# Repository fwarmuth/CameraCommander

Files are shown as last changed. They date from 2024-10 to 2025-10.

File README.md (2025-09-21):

# CameraCommander

Two stepper motors drive pan and tilt. A4988 drivers connect to an ESP8266 (target: ESP32) that keeps motion state and speaks a small serial protocol. A Raspberry Pi Zero 2 runs the Python app: configures the camera via gphoto2, stores images, controls the ESP over serial, and serves a web UI for focus, exposure tests (ISO, aperture), and tripod movement/settings.

What it looks like:

### First moving tripod prototype:
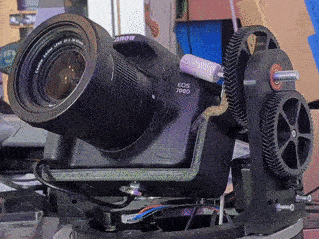
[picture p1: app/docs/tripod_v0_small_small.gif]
Tripod prototype


### Part design (via Freecad):
<!-- ![Top view of the concept](hardware/top.png){width="10px"}
![Buttom view of the concept](hardware/bot.png) -->
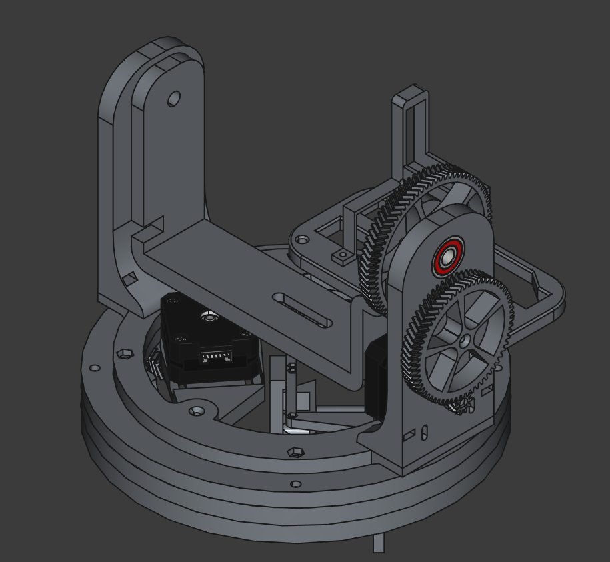
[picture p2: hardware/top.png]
Top view of the concept

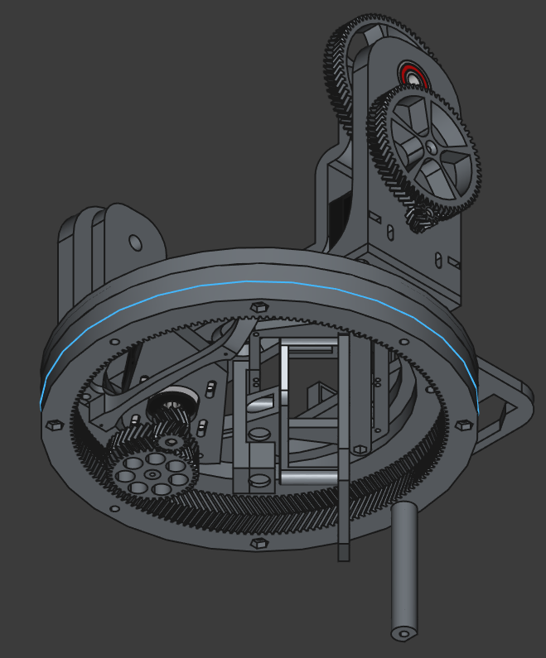
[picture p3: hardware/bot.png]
Bottom view of the concept


### Example result time-lapse:
Just camera controls, north of Kiruna, Sweden.

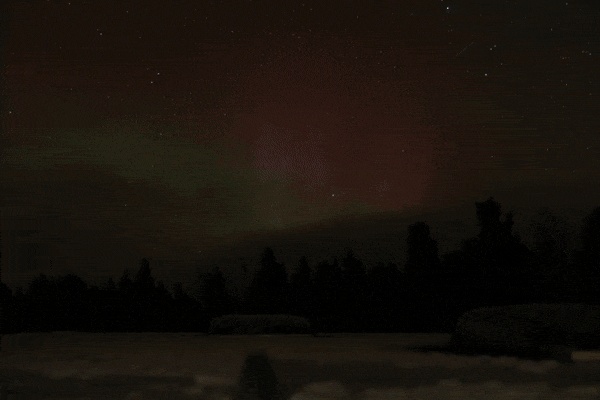
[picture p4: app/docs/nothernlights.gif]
Timelapse example


## Quick Start

- App (Python)
  - Requires: Python 3.11+, libgphoto2, ffmpeg (for video), a serial port for the tripod.
  - Run without installing (uv):
    - `cd app`
    - `uv run cameracommander --help`
  - Or install locally:
    - `cd app`
    - `pip install -e .`
    - `cameracommander --help`
  - Use:
    - Build a config: `cameracommander ui` (opens http://localhost:8000)
    - Test shot: `cameracommander snapshot settings.yaml out.jpg`
    - Timelapse: `cameracommander timelapse settings.yaml`

- Firmware (ESP8266)
  - Requires: PlatformIO CLI, NodeMCU v3 (ESP8266), step/dir drivers (A4988/TMC).
  - From repo root (PlatformIO is configured to use `firmware/src`):
    - Build: `pio run`
    - Flash: `pio upload`
    - Monitor: `pio device monitor`

## Structure

- `app/` — Python CLI and Gradio UI
- `firmware/` — ESP8266 PlatformIO source (`src/`)
- `platformio.ini` — Firmware config (points `src_dir` to `firmware/src`)

## Architecture

- CLI (Typer) loads heavy modules lazily. Commands: `snapshot`, `tripod`, `timelapse`, `ui`.
- Camera control via `gphoto2` (`CameraWrapper`), tripod via serial (`TripodController`).
- Timelapse loop: capture → write metadata → move to next absolute pan/tilt → optional ffmpeg render.
- Gradio UI builds/export YAML configs and can run a short prototype timelapse.

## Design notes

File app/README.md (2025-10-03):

# CameraCommander App

CLI and Gradio UI for time‑lapse capture with a gphoto2 camera and a serial pan/tilt tripod.

Examples:

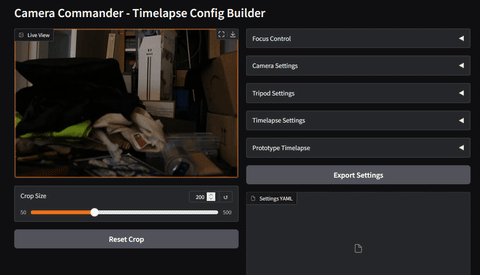
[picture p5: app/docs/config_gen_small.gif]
Config UI


## Setup

- Requires: Python 3.11+, libgphoto2, ffmpeg (for video), serial port for the tripod.
- Run without installing (uv):
  - `uv run cameracommander --help`
- Or install locally:
  - `pip install -e .`
  - `cameracommander --help`

## Use

- UI (build/export configs, prototype runs):
  - `cameracommander ui`  (use `--share` to expose a public link)
  - Opens http://localhost:8000
- Snapshot:
  - `cameracommander snapshot settings.yaml out.jpg`
- Timelapse:
  - `cameracommander timelapse settings.yaml`
- Tripod (interactive):
  - `cameracommander tripod settings.yaml`

Minimal config (YAML):

```yaml
camera:
  main.imgsettings.iso: 100
  main.capturesettings.aperture: 2.8
  main.capturesettings.shutterspeed: "1/60"
  main.imgsettings.whitebalance: Auto

tripod:
  serial: { port: "/dev/ttyUSB0", baudrate: 9600 }  # Windows: "COM3"
  microstep: 16

timelapse:
  total_frames: 100
  interval_s: 10
  settle_time_s: 0.3
  start: { pan: 0.0, tilt: 0.0 }
  target: { pan: 60.0, tilt: 45.0 }
  output_dir: ./output
  render_video: true
  video_fps: 25
```

Notes:
- Video render needs `ffmpeg`. Set `render_video: false` to skip.

## Mock tripod setup

1. Start the mock firmware server:

   ```
   python -m firmware.mock_firmware_server --host 127.0.0.1 --port 9999 --deg-per-second 60
   ```

   Leave the terminal running; stop it with `Ctrl+C` when finished.

2. Use the sample config `app/settings_mock_tripod.yaml`, which points the tripod serial port at `socket://127.0.0.1:9999`.

3. Run any tripod command against that config, e.g.:

   ```
   uv run cameracommander tripod app/settings_mock_tripod.yaml
   ```

The controller logic is identical to talking to the ESP; swap the `serial.port` back to your COM/USB device when you connect real hardware.
## Layout

- `src/cli.py` â€” Typer CLI (lazyâ€‘loads heavy modules)
- `src/camerawrapper.py` â€” gphoto2 wrapper (settings, capture, live view)
- `src/tripodwrapper.py` â€” serial tripod control (absolute moves)
- `src/timelapse.py` â€” capture/move loop, metadata, ffmpeg render
- `src/advanced_live_view/` â€” Gradio UI and helpers

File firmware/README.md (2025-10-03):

# CameraCommander Firmware

ESP8266 firmware for a two‑axis stepper tripod. Simple serial protocol, absolute moves, DONE/S/OK replies.

## Setup

- Requires: PlatformIO CLI, NodeMCU v3 (ESP8266), A4988/TMC step/dir/enable drivers.
- Build/flash/monitor from repo root (PlatformIO points `src_dir` to `firmware/src`):
  - Build: `pio run`
  - Flash: `pio upload`
  - Monitor: `pio device monitor`

## Commands

```
V                            # version
M <pan_deg> <tilt_deg>       # absolute move; replies DONE when finished
S                            # STATUS <pan> <tilt> <drivers 0|1>
1 2 4 8 6                    # microstep (6 == 16)
n/c/r/x                      # pan: step / revolution / toggle dir / stop
w/p/t/z                      # tilt: step / revolution / toggle dir / stop
X                            # stop both axes
+ / -                        # faster / slower (10%)
d / e                        # disable / enable drivers (resets position to 0)
```

## Layout

- `src/GearedStepper.h/.cpp` — AccelStepper wrapper with gearing + microstep control
- `src/main.cpp` — command parser, pin map, motion control
- Pin mapping and mechanics are defined in `src/main.cpp`.

## Mock firmware server

A pure-Python emulator lives in `firmware/mock_firmware_server.py`. It speaks the same
serial protocol as the ESP firmware so you can exercise the desktop app without
hardware attached.

Start it in a shell:

```
python -m firmware.mock_firmware_server --host 127.0.0.1 --port 9999 --deg-per-second 60
```

Then point the tripod configuration at `socket://127.0.0.1:9999`. Adjust
`--deg-per-second` (movement speed) and `--settle-delay` if you want slower or faster
responses. Stop the mock with `Ctrl+C`.

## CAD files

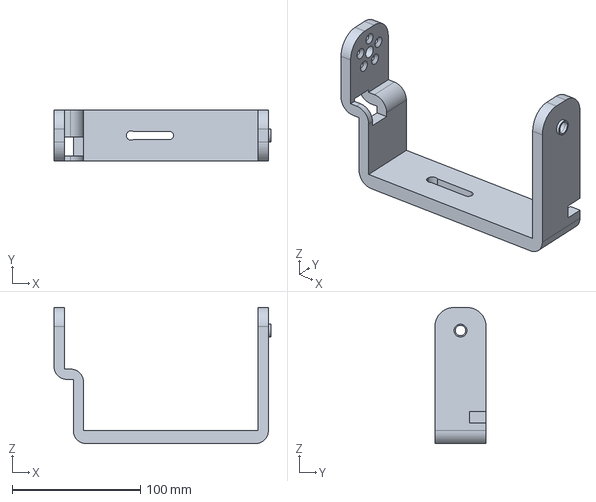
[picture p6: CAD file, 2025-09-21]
hardware/tripod_camera_u.FCStd
169.0 x 40.0 x 106.0 mm

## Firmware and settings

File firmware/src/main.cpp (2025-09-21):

/*
 * ─────────────────────────────────────────────────────────────────────────
 *  Dual-axis turntable – feedback build                    Jul-2025
 *  ----------------------------------------------------------------------
 *  Commands (case-insensitive)
 *  ----------------------------------------------------------------------
 *    V                         … report firmware version
 *    M <pan_deg> <tilt_deg>    : move both axes (absolute degrees) -> DONE
 *    S                         : report absolute pan/tilt and driver state
 *
 *    1 2 4 8 6                 … set micro-step (6 == 16)
 *
 *    n                         … 1 µ-step on pan  (auto-bounce)
 *    c                         … full revolution on pan
 *    r                         … toggle pan direction
 *    x                         … stop pan
 *
 *    w                         … 1 µ-step on tilt (auto-bounce)
 *    p                         … full revolution on tilt
 *    t                         … toggle tilt direction
 *    z                         … stop tilt
 *
 *    X                         … stop BOTH axes
 *
 *    + / −                     … increase / decrease common output speed 10 %
 *
 *    d / e                     … disable / enable both drivers
 *  ----------------------------------------------------------------------
 *  Every accepted command replies:
 *      VERSION x.y.z   |  DONE   |  OK ...   |  ERR ...
 *  ----------------------------------------------------------------------
 */

#include <Arduino.h>
#include "GearedStepper.h"

/* ─── Firmware version ─────────────────────────────────────────────── */
#define FW_VERSION "1.0.1"

/* ─── Pin mapping (NodeMCU v3) ─────────────────────────────────────── */
#define TT_STEP_PIN     D4
#define TT_DIR_PIN      D5
#define TT_ENABLE_PIN   D0

#define VT_STEP_PIN     D6
#define VT_DIR_PIN      D7
#define VT_ENABLE_PIN   D8

#define MS1_PIN         D1
#define MS2_PIN         D2
#define MS3_PIN         D3

/* ─── Mechanics ────────────────────────────────────────────────────── */
constexpr long  MOTOR_STEPS_PER_REV = 200;
constexpr float GEAR_RATIO_TT       = 11.335f;
constexpr float GEAR_RATIO_VT       = 6.2f * 7.5f;

/* ─── Stepper instances ────────────────────────────────────────────── */
GearedStepper turntableStepper(
    TT_STEP_PIN, TT_DIR_PIN, TT_ENABLE_PIN,
    MS1_PIN, MS2_PIN, MS3_PIN,
    MOTOR_STEPS_PER_REV, GEAR_RATIO_TT);

GearedStepper tiltStepper(
    VT_STEP_PIN, VT_DIR_PIN, VT_ENABLE_PIN,
    MS1_PIN, MS2_PIN, MS3_PIN,
    MOTOR_STEPS_PER_REV, GEAR_RATIO_VT);

/* ─── Axis bookkeeping ────────────────────────────────────────────── */
struct Axis { GearedStepper& s; int dir = 1; };
Axis rot { turntableStepper };
Axis til { tiltStepper     };

/* ─── Helpers ──────────────────────────────────────────────────────── */
inline void ack(const char*  msg) { Serial.println(msg); }
inline void ack(const String& msg) { Serial.println(msg); }

long degToMicrosteps(GearedStepper& stp, float deg)
{
    long µ = stp.getOutputStepsPerRotation() *
             stp.getMicrostepResolution();
    return lroundf(deg / 360.0f * µ);
}

float microstepsToDeg(const GearedStepper& stp, long steps)
{
    long stepsPerRev = stp.getOutputStepsPerRotation() * stp.getMicrostepResolution();
    if (stepsPerRev == 0) {
        return 0.0f;
    }
    return static_cast<float>(steps) * 360.0f / static_cast<float>(stepsPerRev);
}

constexpr float RATIO_TT_TO_VT = GEAR_RATIO_VT / GEAR_RATIO_TT;
constexpr float ROT_SPEED0 = 150.0f, ROT_ACCEL0 = 80.0f;
static float gRotSpeed = ROT_SPEED0;
static float gRotAccel = ROT_ACCEL0;
static bool gDriversEnabled = true;

void setRotaryMotorSpeed(float v, float a)
{
    turntableStepper.setMaxSpeed(v);
    turntableStepper.setAcceleration(a);
    tiltStepper.setMaxSpeed(v * RATIO_TT_TO_VT);
    tiltStepper.setAcceleration(a * RATIO_TT_TO_VT);
}

/* ─── setup() ──────────────────────────────────────────────────────── */
void setup()
{
    Serial.begin(9600);
    delay(200);

    rot.s.begin(); til.s.begin();
    turntableStepper.setCurrentPosition(0);
    turntableStepper.moveTo(0);
    tiltStepper.setCurrentPosition(0);
    tiltStepper.moveTo(0);
    gDriversEnabled = true;
    setRotaryMotorSpeed(gRotSpeed, gRotAccel);

    /* full command list on boot */
    Serial.println(F(
      "Dual-axis turntable – firmware " FW_VERSION "\n"
      "--------------------------------------------------\n"
      "  V                         : firmware version\n"
      "  M <pan> <tilt>            : move axes absolute (deg) -> DONE\n"
      "  S                         : status (pan tilt enable)\n"
      "  1 2 4 8 6                 : set micro-step (6=16)\n"
      "  n c r x                   : step / rev / dir / stop pan\n"
      "  w p t z                   : step / rev / dir / stop tilt\n"
      "  X                         : stop both axes\n"
      "  + / -                     : faster / slower\n"
      "  d / e                     : disable / enable drivers\n"
      "--------------------------------------------------"
    ));
}

/* ─── loop() ────────────────────────────────────────────────────────── */
void loop()
{
    /* keep steppers running */
    turntableStepper.run(); tiltStepper.run();
    if (!Serial.available()) return;

    /* read full line */
    String line = Serial.readStringUntil('\n');
    line.trim();
    if (!line.length()) return;
    char c = line.charAt(0);

    /* -------- Version ------------------------------------------------ */
    if (c == 'V' || c == 'v') { ack(String("VERSION ") + FW_VERSION); return; }

    /* -------- Move  M pan tilt --------------------------------------- */
    if (c == 'M' || c == 'm') {
        float panDeg = 0, tiltDeg = 0;
        if (sscanf(line.c_str() + 1, "%f %f", &panDeg, &tiltDeg) != 2) {
            ack("ERR Syntax"); return;
        }
        long targetPan = degToMicrosteps(turntableStepper, panDeg);
        long targetTilt = degToMicrosteps(tiltStepper,    tiltDeg);
        long deltaPan = targetPan - turntableStepper.currentPosition();
        long deltaTilt = targetTilt - tiltStepper.currentPosition();
        if (deltaPan == 0 && deltaTilt == 0) {
            ack("DONE"); return;
        }
        turntableStepper.move(deltaPan);
        tiltStepper.move(deltaTilt);
        while (turntableStepper.distanceToGo() || tiltStepper.distanceToGo()) {
            turntableStepper.run();
            tiltStepper.run();
            yield();
        }
        delay(250); // Settle time
        ack("DONE"); return;
    }

    if (c == 'S' || c == 's') {
        float panDeg = microstepsToDeg(turntableStepper, turntableStepper.currentPosition());
        float tiltDeg = microstepsToDeg(tiltStepper, tiltStepper.currentPosition());
        ack(String("STATUS ") + String(panDeg, 3) + " " + String(tiltDeg, 3) + " " + (gDriversEnabled ? "1" : "0"));
        return;
    }

    /* -------- μ-step -------------------------------------------------- */
    if (strchr("12486", c)) {
        int res = (c == '6') ? 16 : (c - '0');
        turntableStepper.setMicrostepResolution(res);
        tiltStepper.setMicrostepResolution(res);
        ack(String("OK MICROSTEP ") + res); return;
    }

    /* -------- Pan axis (rot) ----------------------------------------- */
    switch (c) {
        case 'n': case 'N': rot.s.move(rot.dir);                    ack("OK ROT STEP"); return;
        case 'c': case 'C': {
            long r = rot.s.getOutputStepsPerRotation() *
                     rot.s.getMicrostepResolution();
            rot.s.move(rot.dir * r);                                ack("OK ROT REV");  return;
        }
        case 'r': case 'R': rot.dir = -rot.dir;                     ack("OK ROT DIR");  return;
        case 'x':           rot.s.stop();                           ack("OK ROT STOP"); return;
    }

    /* -------- Tilt axis (til) ---------------------------------------- */
    switch (c) {
        case 'w': case 'W': til.s.move(til.dir);                    ack("OK TILT STEP"); return;
        case 'p': case 'P': {
            long r = til.s.getOutputStepsPerRotation() *
                     til.s.getMicrostepResolution();
            til.s.move(til.dir * r);                                ack("OK TILT REV");  return;
        }
        case 't': case 'T': til.dir = -til.dir;                     ack("OK TILT DIR");  return;
        case 'z':           til.s.stop();                           ack("OK TILT STOP"); return;
    }

    /* -------- Speed adjust ------------------------------------------- */
    if (c == '+' || c == '-') {
        float f = (c == '+') ? 1.10f : 0.90f;
        gRotSpeed *= f;
        gRotAccel *= f;
        setRotaryMotorSpeed(gRotSpeed, gRotAccel);
        ack("OK SPEED"); return;
    }

    /* -------- Global stop -------------------------------------------- */
    if (c == 'X') { rot.s.stop(); til.s.stop(); ack("OK STOP"); return; }

    /* -------- Driver enable / disable -------------------------------- */
    if (c == 'd' || c == 'D') {
        turntableStepper.disable();
        tiltStepper.disable();
        turntableStepper.setCurrentPosition(0);
        tiltStepper.setCurrentPosition(0);
        gDriversEnabled = false;
        ack("OK DRIVERS OFF");
        return;
    }
    if (c == 'e' || c == 'E') {
        turntableStepper.enable();
        tiltStepper.enable();
        turntableStepper.setCurrentPosition(0);
        tiltStepper.setCurrentPosition(0);
        gDriversEnabled = true;
        ack("OK DRIVERS ON");
        return;
    }

    /* -------- Unknown ------------------------------------------------ */
    ack("ERR Unknown");
}

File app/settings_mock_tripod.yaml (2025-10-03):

camera:
  main.imgsettings.iso: 100
  main.capturesettings.aperture: 2.8
  main.capturesettings.shutterspeed: "1/60"
  main.imgsettings.whitebalance: Auto

tripod:
  serial:
    port: socket://127.0.0.1:9999
    baudrate: 9600
    timeout: 1.0
    write_timeout: 1.0
    reconnect_interval: 1.0
    max_retries: 5
  microstep: 1

mock_firmware:
  host: 127.0.0.1
  port: 9999
  deg_per_second: 60
  settle_delay: 0.25

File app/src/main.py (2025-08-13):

from camerawrapper import CameraWrapper
from pathlib import Path
import time
import logging

logger = logging.getLogger(__name__)

# ------------------------------------------------------------------------- #
# Demonstration
# ------------------------------------------------------------------------- #
if __name__ == "__main__":
    # 1. Discover cameras
    cams = CameraWrapper.discover_cameras()
    print("Discovered:", cams)

    # 2. Pick the first Canon body found
    cam = CameraWrapper.select_camera("canon")
    print("Selected:", cam._model)


    # Test manual focus:
    def focus_step(cam, direction="near", size=1):
        """
        direction = 'near' | 'far'
        size      = 1, 2 or 3   (larger = bigger rotation)
        """
        if direction not in ("near", "far"):
            raise ValueError("direction must be 'near' or 'far'")
        if size not in (1, 2, 3):
            raise ValueError("size must be 1, 2 or 3")
        label = f"{direction.capitalize()} {size}"
        cam.apply_settings({"main.actions.manualfocusdrive": label})
    pass
    cam.apply_settings({"main.actions.viewfinder": "0"})
    cam.capture_image(Path("focus_test/base_iso_auto.jpg"))
    for i in range(10):
        cam.apply_settings({"main.actions.viewfinder": "1"})
        time.sleep(0.1)
        focus_step(cam, "near", 3)
        cam.apply_settings({"main.actions.viewfinder": "0"})
        time.sleep(0.2)
        cam.capture_image(Path(f"focus_test/near_{i}.jpg"))

        

    # 3. Change ISO then capture
    print("Current ISO:", cam.get_current_settings().get("main.imgsettings.iso", "?"))
    img_path = cam.capture_image(Path("aaaa/iso_auto.jpg"))
    cam.apply_settings({"main.imgsettings.iso": "100"})
    img_path = cam.capture_image(Path("aaaa/iso_100.jpg"))

    # auto adjust
    cam.apply_settings({
                        "main.imgsettings.iso": "800",
                        "main.capturesettings.aperture": "5.6",
                        "main.capturesettings.shutterspeed": "1/80"
                        })
    cam.capture_image(Path("aaaa/auto_adjust.jpg"))


    # # Keep script alive a moment for async demo
    # time.sleep(10)
    
    # from tripodwrapper import TripodController, configure_logging
    # configure_logging(logging.DEBUG)
    # tripod = TripodController({"port": "/dev/ttyUSB0", "baudrate": 9600})
    # tripod.enable_drivers(True)
    # tripod.set_microstep(8)
    # tripod.move(15,-5)
    # while tripod.query_busy():   # poll firmware “Q”
    #     pass
    # tripod.set_microstep(16)
    # tripod.move_blocking(-15,5)
    # print(tripod.position)
    # tripod.close()
    

    # if len(sys.argv) != 2:
    #     print("Usage: python timelapse_session.py <config.yml|json>")
    #     sys.exit(1)

    # session = TimelapseSession(sys.argv[1])

    # def _progress(done: int, total: int) -> None:
    #     pct = done / total * 100
    #     print(f"\rCaptured {done}/{total} frames ({pct:5.1f} %)", end="", flush=True)

    # try:
    #     video = session.run(_progress)
    #     print(f"\nDone! Video at {video}")
    # except TimelapseError as exc:
    #     logger.error("Timelapse failed: %s", exc)
    #     sys.exit(2)

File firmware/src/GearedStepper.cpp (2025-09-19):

#include "GearedStepper.h"
#include <math.h>   // lroundf()

/* ── Constructor ─────────────────────────────────────────────────────── */
GearedStepper::GearedStepper(uint8_t step_pin, uint8_t dir_pin, uint8_t enable_pin,
                             uint8_t ms1_pin,  uint8_t ms2_pin,  uint8_t ms3_pin,
                             long    base_steps_per_rot,
                             float   gear_ratio)
    : _enable_pin(enable_pin),
      _ms1_pin(ms1_pin),
      _ms2_pin(ms2_pin),
      _ms3_pin(ms3_pin),
      _base_steps_per_rot(base_steps_per_rot),
      _gear_ratio(gear_ratio),
      _microstep_resolution(1),      // default = full-step
      _stepper(AccelStepper::DRIVER, step_pin, dir_pin)
{
    /* STEP and DIR are already OUTPUT by AccelStepper */
}

/* ── Life-cycle ───────────────────────────────────────────────────────── */
void GearedStepper::begin() {
    pinMode(_enable_pin, OUTPUT);
    pinMode(_ms1_pin,    OUTPUT);
    pinMode(_ms2_pin,    OUTPUT);
    pinMode(_ms3_pin,    OUTPUT);

    setMicrostepResolution(_microstep_resolution);
    enable();
}

/* ── Motion control passthroughs ──────────────────────────────────────── */
void GearedStepper::setMaxSpeed(float s)          { _stepper.setMaxSpeed(s); }
void GearedStepper::setAcceleration(float a)      { _stepper.setAcceleration(a); }
void GearedStepper::moveTo(long absPos)           { _stepper.moveTo(absPos); }
void GearedStepper::move(long rel)                { _stepper.move(rel); }
bool GearedStepper::run()                         { return _stepper.run(); }
void GearedStepper::runToPosition()               { _stepper.runToPosition(); }
void GearedStepper::stop()                        { _stepper.stop(); }

long GearedStepper::currentPosition()             { return _stepper.currentPosition(); }
void GearedStepper::setCurrentPosition(long p)    { _stepper.setCurrentPosition(p); }
long GearedStepper::distanceToGo()                { return _stepper.distanceToGo(); }
long GearedStepper::targetPosition()              { return _stepper.targetPosition(); }
bool GearedStepper::isRunning()                   { return _stepper.isRunning(); }


/* ── Driver enable/disable ────────────────────────────────────────────── */
void GearedStepper::enable()  { digitalWrite(_enable_pin, LOW);  }
void GearedStepper::disable() { digitalWrite(_enable_pin, HIGH); }

/* ── Micro-step handling ──────────────────────────────────────────────── */
void GearedStepper::setMicrostepResolution(int res)
{
    _microstep_resolution = res;
    switch (res) {
        case 1:  digitalWrite(_ms1_pin, LOW ); digitalWrite(_ms2_pin, LOW ); digitalWrite(_ms3_pin, LOW ); break;
        case 2:  digitalWrite(_ms1_pin, HIGH); digitalWrite(_ms2_pin, LOW ); digitalWrite(_ms3_pin, LOW ); break;
        case 4:  digitalWrite(_ms1_pin, LOW ); digitalWrite(_ms2_pin, HIGH); digitalWrite(_ms3_pin, LOW ); break;
        case 8:  digitalWrite(_ms1_pin, HIGH); digitalWrite(_ms2_pin, HIGH); digitalWrite(_ms3_pin, LOW ); break;
        case 16: digitalWrite(_ms1_pin, HIGH); digitalWrite(_ms2_pin, HIGH); digitalWrite(_ms3_pin, HIGH); break;
    }
}
int GearedStepper::getMicrostepResolution() const { return _microstep_resolution; }

/* ── Gearbox helpers ──────────────────────────────────────────────────── */
float GearedStepper::getGearRatio() const               { return _gear_ratio; }
long  GearedStepper::getBaseStepsPerRotation() const     { return _base_steps_per_rot; }
float GearedStepper::maxSpeed()                        { return _stepper.maxSpeed(); }
float GearedStepper::acceleration()                    { return _stepper.acceleration(); }
long  GearedStepper::getOutputStepsPerRotation() const
{
    return lroundf(_base_steps_per_rot * _gear_ratio);
}

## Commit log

2025-07-26 Current state
2025-07-26 Add new camerawrapper
2025-08-02 feat: expose camera settings in live view
2025-08-02 Fix threading
2025-08-03 Fix thread
2025-08-15 Try to fix cli
    [cli.py]
2025-09-20 Add disable and enable driver in tripod cli.
2025-09-21 Enable driver at init
2025-09-21 Add enable switch and better layout for tripod settings
2025-09-21 Fix button update
2025-09-21 Add status button
2025-09-21 Track FreeCAD binaries with LFS (+locking)
2025-09-21 Add current 3D model files echo "*.FCStd filter=lfs diff=lfs merge=lfs -text" >> .gitattributes echo "*.FCStd lockable" >> .gitattributes git add .gitattributes git commit -m "Track FreeCAD binaries 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
    [tripod_camera_u.FCStd]
